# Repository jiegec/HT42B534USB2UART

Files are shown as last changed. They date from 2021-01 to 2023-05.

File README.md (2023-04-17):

# HT42B534 USB 2 UART Board

A simple USB to UART board. Designed with KiCad. Manufactured and tested.

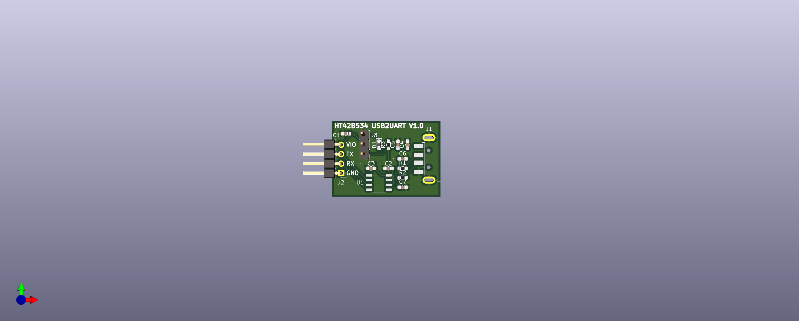
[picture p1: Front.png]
Front

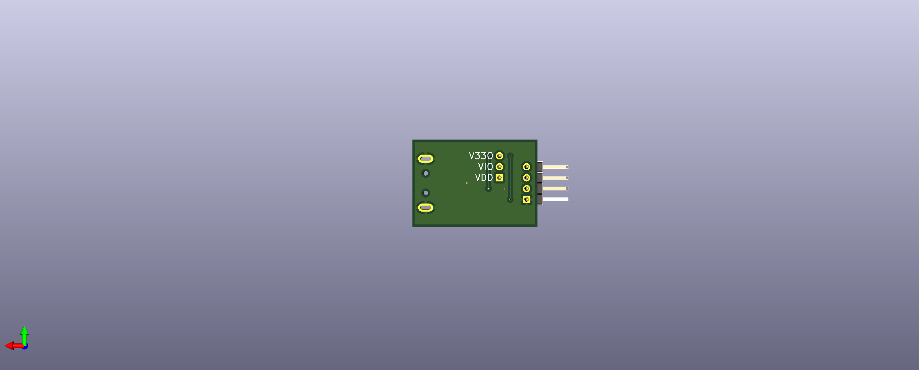
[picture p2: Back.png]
Back


## How to use

1. Plug USB to your PC
2. Wire VIO to either V33O(3.3V) or VDD(5V)
3. Connect TX, RX & GND (optionally VIO) to other devices

The voltage of RX/TX should match VIO.

## Bill of Materials

```csv
Reference, Value, Footprint, Datasheet, Product
"U1","HT42B534_8SOP","Package_SO:SOP-8_3.9x4.9mm_P1.27mm","https://www.holtek.com/documents/10179/116711/HT42B534-xv110.pdf","https://item.szlcsc.com/504007.html"
"C1","0.1uF","Capacitor_SMD:C_0603_1608Metric_Pad1.08x0.95mm_HandSolder","~"
"J1","USB_A","Connector_USB:USB_A_CNCTech_1001-011-01101_Horizontal","~","https://item.szlcsc.com/98530.html"
"R2","33","Resistor_SMD:R_0603_1608Metric_Pad0.98x0.95mm_HandSolder","~"
"R1","33","Resistor_SMD:R_0603_1608Metric_Pad0.98x0.95mm_HandSolder","~"
"C6","47pF","Capacitor_SMD:C_0603_1608Metric_Pad1.08x0.95mm_HandSolder","~"
"C7","47pF","Capacitor_SMD:C_0603_1608Metric_Pad1.08x0.95mm_HandSolder","~"
"C3","1uF","Capacitor_SMD:C_0603_1608Metric_Pad1.08x0.95mm_HandSolder","~"
"C2","0.1uF","Capacitor_SMD:C_0603_1608Metric_Pad1.08x0.95mm_HandSolder","~"
"C4","10uF","Capacitor_SMD:C_0603_1608Metric_Pad1.08x0.95mm_HandSolder","~"
"C5","0.1uF","Capacitor_SMD:C_0603_1608Metric_Pad1.08x0.95mm_HandSolder","~"
"R3","330","Resistor_SMD:R_0603_1608Metric_Pad0.98x0.95mm_HandSolder","~"
"D1","LED","Diode_SMD:D_0603_1608Metric_Pad1.05x0.95mm_HandSolder","~"
"J3","Conn_01x03","Connector_PinHeader_2.54mm:PinHeader_1x03_P2.54mm_Vertical","~"
"J2","Conn_01x04","Connector_PinHeader_2.54mm:PinHeader_1x04_P2.54mm_Horizontal","~"
```

## USB Device Info

`lsusb` output:

```shell
$ lsusb
Bus 000 Device 001: ID 04d9:b534 Holtek Semiconductor, Inc. USB TO UART BRIDGE  Serial: 0000
```

System Information:

```
USB TO UART BRIDGE:

  Product ID:	0xb534
  Vendor ID:	0x04d9  (Holtek Semiconductor, Inc.)
  Version:	2.10
  Serial Number:	0000
  Speed:	Up to 12 Mb/s
  Manufacturer:	HOLTEK
  Location ID:	0x00142000 / 12
  Current Available (mA):	500
  Current Required (mA):	100
  Extra Operating Current (mA):	0
```

## License

Copyright 2020-2021 Jiajie Chen

SPDX-License-Identifier: Apache-2.0 WITH SHL-2.1

Licensed under the Solderpad Hardware License v 2.1 (the “License”); you may not use this file except in compliance with the License, or, at your option, the Apache License version 2.0. You may obtain a copy of the License at

https://solderpad.org/licenses/SHL-2.1/

Unless required by applicable law or agreed to in writing, any work distributed under the License is distributed on an “AS IS” BASIS, WITHOUT WARRANTIES OR CONDITIONS OF ANY KIND, either express or implied. See the License for the specific language governing permissions and limitations under the License.

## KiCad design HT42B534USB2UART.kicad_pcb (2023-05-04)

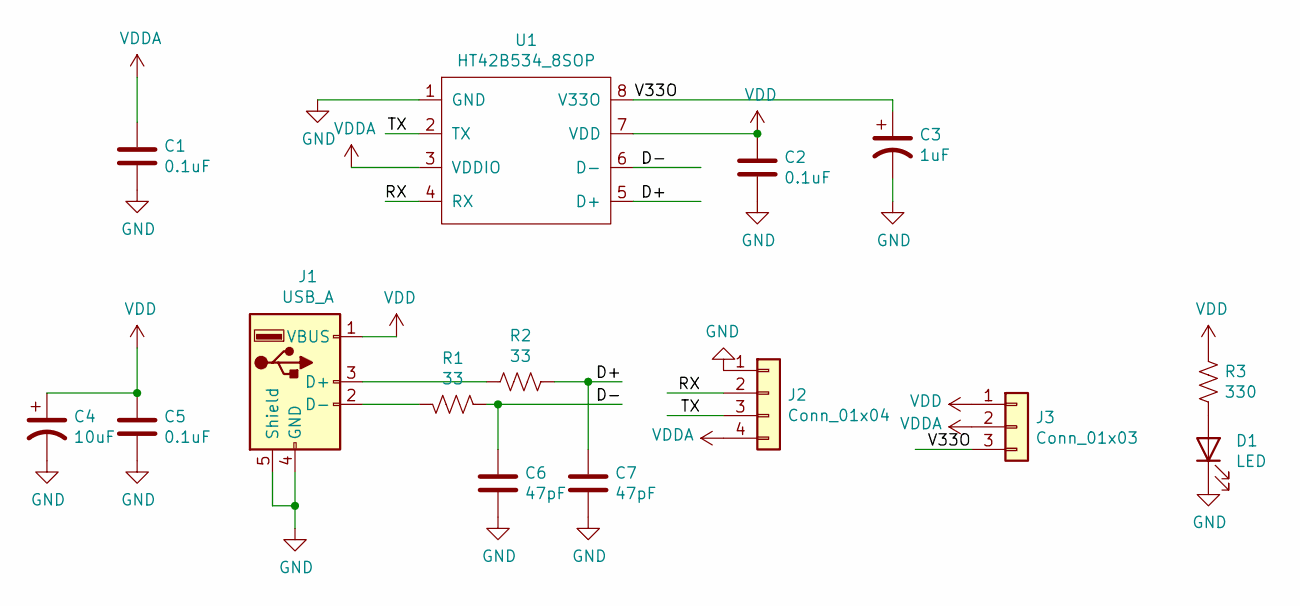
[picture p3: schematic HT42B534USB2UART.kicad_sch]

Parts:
C1, C2, C5: 0.1uF; C_0603_1608Metric_Pad1.08x0.95mm_HandSolder
C3: 1uF; C_0603_1608Metric_Pad1.08x0.95mm_HandSolder
C4: 10uF; C_0603_1608Metric_Pad1.08x0.95mm_HandSolder
C6, C7: 47pF; C_0603_1608Metric_Pad1.08x0.95mm_HandSolder
D1: LED; D_0603_1608Metric_Pad1.05x0.95mm_HandSolder
J1: USB_A; USB_A_CNCTech_1001-011-01101_Horizontal
J2: Conn_01x04; PinHeader_1x04_P2.54mm_Horizontal
J3: Conn_01x03; PinHeader_1x03_P2.54mm_Vertical
R1, R2: 33; R_0603_1608Metric_Pad0.98x0.95mm_HandSolder
R3: 330; R_0603_1608Metric_Pad0.98x0.95mm_HandSolder
U1: HT42B534_8SOP; SOP-8_3.9x4.9mm_P1.27mm

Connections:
/D+: C7.1, R2.1, U1.5 (D+)
/D-: C6.1, R1.1, U1.6 (D-)
/RX: J2.2, U1.4 (RX)
/TX: J2.3, U1.2 (TX)
/V33O: C3.1, J3.3, U1.8 (V33O)
GND: C1.2, C2.2, C3.2, C4.2, C5.2, C6.2, C7.2, D1.1 (K), J1.4 (GND), J1.5 (Shield), J2.1, U1.1 (GND)
unnamed: D1.2 (A), R3.2
unnamed: J1.2 (D-), R1.2
unnamed: J1.3 (D+), R2.2
VDD: C2.1, C4.1, C5.1, J1.1 (VBUS), J3.1, R3.1, U1.7 (VDD)
VDDA: C1.1, J2.4, J3.2, U1.3 (VDDIO)

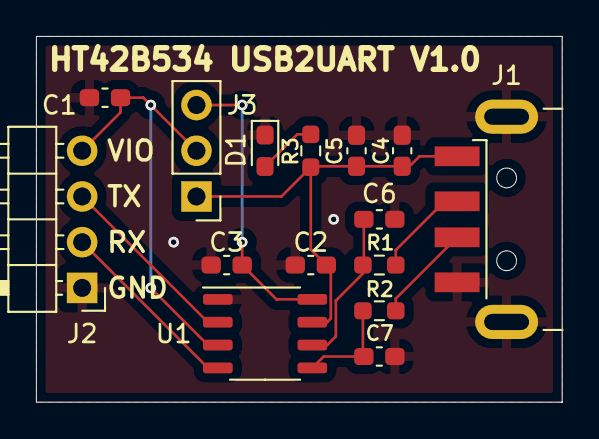
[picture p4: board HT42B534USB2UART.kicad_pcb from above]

Board: 2 copper layers, 29.2 x 20.3 mm, 15 parts (0 on the bottom side), 11 nets.

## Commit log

2020-12-27 Initial version of HT42B534 USB to UART board
    [HT42B534USB2UART-B_Cu.gbr, HT42B534USB2UART-B_Mask.gbr, HT42B534USB2UART-B_Paste.gbr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]
2020-12-28 Setup board parameters(track width, via size etc) and use filled Cu layers
    [HT42B534USB2UART-B_Cu.gbr, HT42B534USB2UART-B_Mask.gbr, HT42B534USB2UART-B_Paste.gbr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]
2020-12-28 Add slik text
    [HT42B534USB2UART-B_Cu.gbr, HT42B534USB2UART-B_Mask.gbr, HT42B534USB2UART-B_Paste.gbr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]
2020-12-28 Add a conn01x03 for voltage selection
    [HT42B534USB2UART-B_Cu.gbr, HT42B534USB2UART-B_Mask.gbr, HT42B534USB2UART-B_Paste.gbr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]
2020-12-28 Move gerber files to subdir
    [HT42B534USB2UART-B_Cu.gbr, HT42B534USB2UART-B_Mask.gbr, HT42B534USB2UART-B_Paste.gbr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]
2020-12-28 Add missing drill file
    [HT42B534USB2UART-B_Cu.gbr, HT42B534USB2UART-B_Mask.gbr, HT42B534USB2UART-B_Paste.gbr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]
2021-01-02 Use custom symbol library
    [HT42B534USB2UART.kicad_pcb, HT42B534USB2UART.sch]
2021-01-03 Minor update
    [HT42B534USB2UART.sch]
2021-01-03 Fix extra whitespace
    [HT42B534USB2UART.sch]
2021-12-29 Kicad 6.0
    [HT42B534USB2UART.kicad_pcb, HT42B534USB2UART.kicad_sch, HT42B534USB2UART.sch]
2021-12-29 Make text smaller and regenerate gerber
    [HT42B534USB2UART-B_Cu.gbr, HT42B534USB2UART-B_Mask.gbr, HT42B534USB2UART-B_Paste.gbr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]
2023-05-04 Bump kicad version
    [HT42B534USB2UART.kicad_pcb, HT42B534USB2UART.kicad_sch]
